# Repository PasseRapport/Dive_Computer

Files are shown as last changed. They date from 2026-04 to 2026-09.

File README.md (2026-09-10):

# Freediving Computer

<p align="center">
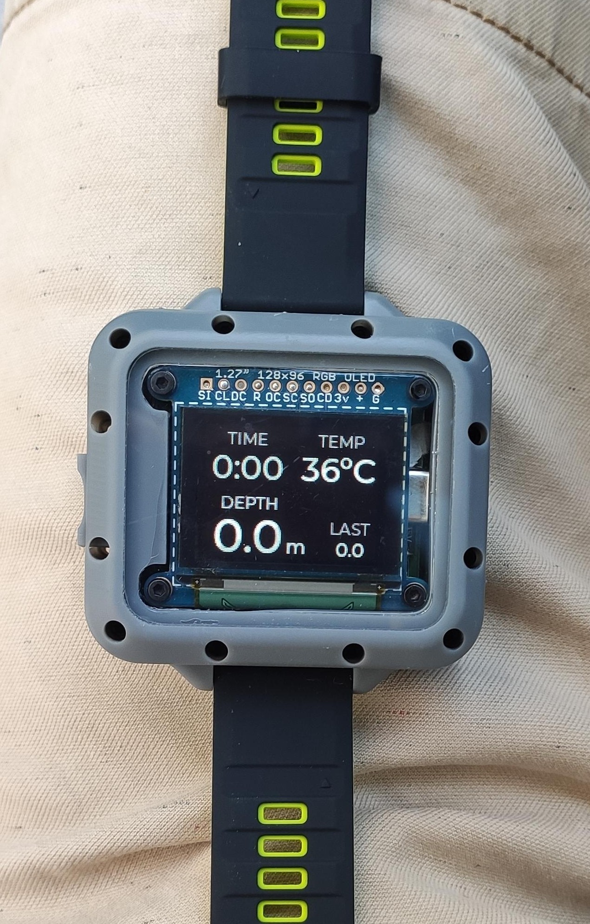
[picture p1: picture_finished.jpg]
Freediving Computer Prototype
  
</p>

A freediving computer prototype I built to test two main ideas: **tap navigation via accelerometer** and **wireless charging** in a completely sealed case.

As a maker, building waterproof buttons and moving parts that survive water pressure without leaking is nearly impossible. To avoid leaks, I skipped physical buttons and external connectors entirely:
1. **Tap navigation** — tapping the case scrolls and selects menus; the accelerometer detects the shock direction.
2. **Wireless charging** — sealed inside the case with an LTC4120 receiver, powered by a custom induction dock.
3. **Magnetic power switch** — an external magnet disconnects the battery so it doesn't drain when stored.
4. **Custom 4-layer PCB** — designed around the form factor of an off-the-shelf color OLED module.

> **Status**: This V1 worked and proved the concept. I am now working on a **V2** that is more compact, with better integration and additional features.

---

## Demo

<p align="center">
  UI Navigation Demo
</p>

<p align="center"><em>Tap-based navigation through the interface — accelerometer detects directional impacts on the casing.</em></p>

<p align="center">
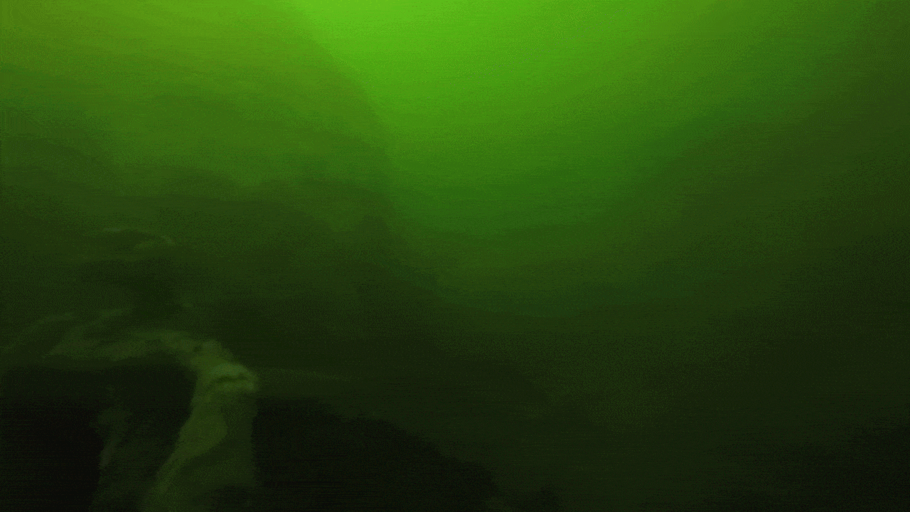
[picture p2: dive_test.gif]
Dive Test
  
</p>

<p align="center"><em>Live depth tracking during a test — automatic dive detection and surface recovery timer.</em></p>

---

## Key Features

| Category | Details |
|---|---|
| **Depth & Temperature** | Real-time tracking via MS5837-30BA (±2 mm resolution, 300–1200 hPa). Automatic fresh/salt water density compensation. |
| **Dive State Machine** | Auto-triggers at 1.0 m depth. Tracks dive time, max depth per dive, and session statistics. |
| **Surface Recovery Timer** | Starts automatically on surfacing. Color-coded: red until 2× dive time, then green. Auto-hides after 10 min. |
| **Session Statistics** | Max dive time, max depth, total dives, and device run time — all tracked per session. |
| **Tap Navigation** | LIS2DUX12 accelerometer detects directional taps on the casing. Left/right to scroll, down to select. No buttons, no dynamic seals. |
| **Magnetic Battery Cutoff** | Integrated magnetic switch isolates the LiPo battery with an external magnet (true 0 µA shelf storage while sealed). |
| **Wireless Charging** | Completely sealed enclosure — power delivered through the case via LTC4120 wireless power receiver. |
| **Display** | 1.27" SSD1351 color OLED (128×96), driven over SPI with DMA. LVGL handles 60 fps animated transitions. |
| **Battery Monitoring** | ADC with hardware calibration curve. Voltage divider maps LiPo range (3.0–4.2 V) to percentage. |
| **Deep Sleep** | Full power-off via menu. GPIO wakeup from accelerometer interrupt. OLED and SPI bus shut down cleanly. |

---

## Mechanical Design

The housing is a two-part sandwich assembly designed without push-buttons, external connectors, or dynamic seals. Waterproofing relies entirely on static seals: a perimeter O-ring evenly compressed between the two halves by 12 M2 screws, and a front protective glass bonded with UV-cure resin. The only physical control is an external magnetic slider that switches power through the solid case wall without any hull penetration.

<p align="center">
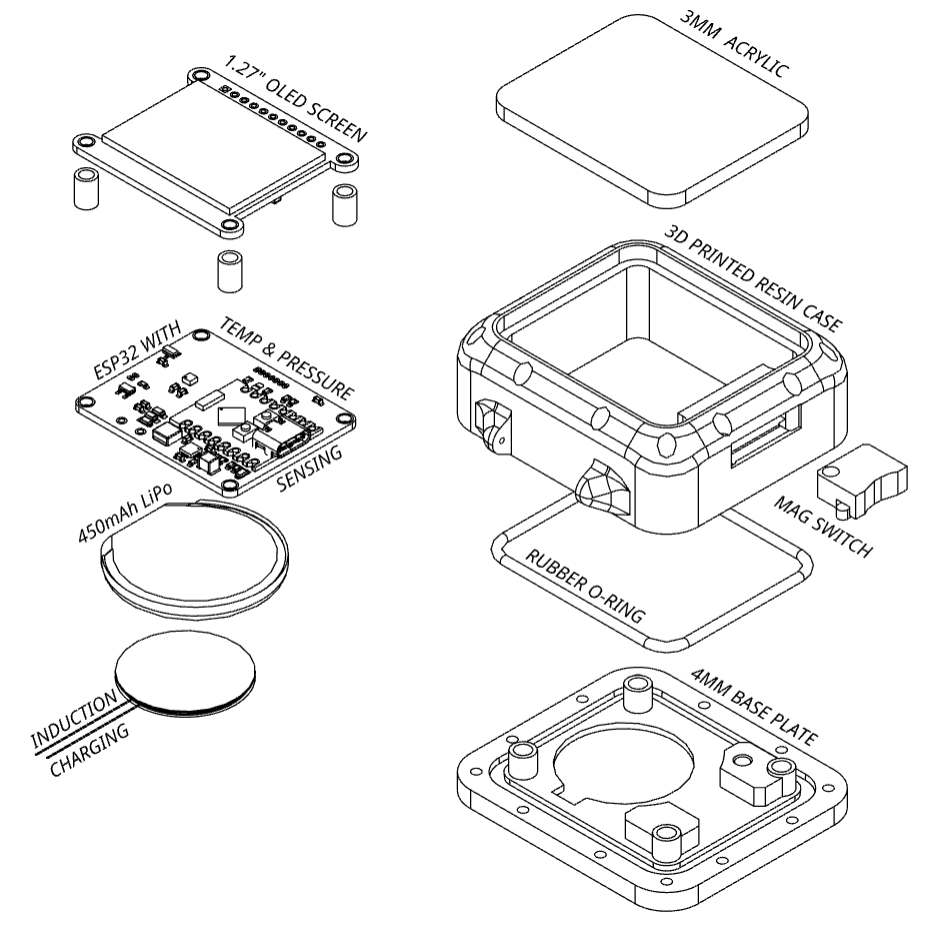
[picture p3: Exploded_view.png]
Exploded View of the Enclosure
  
</p>

<p align="center">
  <a href="https://cad.onshape.com/documents/cc2f090fad22f578b68190d0/w/ffbf50c58a8e366da5acdcdc/e/88baec5796e801b1a2b4a1f3">
    View the 3D model on Onshape ↗
  </a>
</p>

---

## Hardware Architecture

The electronics are split between the wrist unit and a dedicated charging dock.

### 1. Dive Computer Board (Wrist Unit)

The core electronics are built around a custom **4-layer PCB** designed in KiCad, dimensioned to mate directly with an off-the-shelf color OLED module:

- **Form Factor & Display**: Sourced a compact 1.27" 128×96 color OLED module (SSD1351 controller, SPI) and tailored the custom 4-layer PCB and enclosure footprint around this geometry.
- **MCU**: ESP32-C3 (RISC-V core, low power modes, BLE).
- **Pressure Sensor**: TE MS5837-30BA (gel-protected submersible pressure & temperature sensor on I2C).
- **Accelerometer**: ST LIS2DUX12 (ultra-low-power, configured for shock/tap detection with hardware interrupt).
- **Wireless Power Receiver**: Analog Devices LTC4120 with an internal Würth planar receiver coil (WE-WPCC-RX), delivering CC/CV charging to the internal 3.7V LiPo cell.
- **Magnetic Power Switch**: Integrated Hall-effect sensor / magnetic switch controlling a P-MOSFET gate, enabling complete physical battery disconnection via an external magnet without unsealing the housing.

| Component | Part | Role |
|---|---|---|
| MCU | ESP32-C3 | RISC-V core, sensor aggregation, LVGL rendering |
| Pressure Sensor | MS5837-30BA | Absolute pressure & temperature (I2C @ 100 kHz) |
| Accelerometer | LIS2DUX12 | Tap detection with hardware interrupt (I2C) |
| Wireless Charger RX | LTC4120 | Wireless power receiver & CC/CV LiPo charger |
| Magnetic Disconnect | A1102 + P-MOS | Physical battery isolation via external magnet (0 µA storage) |
| Display Module | SSD1351 (Off-the-shelf) | 1.27" 128×96 color OLED (SPI with DMA) |
| Battery | LiPo 3.7V | Single cell, monitored via calibrated ADC voltage divider |

### 2. Wireless Charger Dock (Transmitter)

A companion transmitter base powered via USB-C:

| Component | Part | Role |
|---|---|---|
| Transmitter IC | LTC4125 | 5W AutoResonant wireless power transmitter |
| Transmit Coil | Würth WE-WPCC-TX | 24 µH primary coil for inductive power transfer |
| Input | USB-C (5V) | Power supply |

Source files (KiCad projects, gerbers, BOM): [`Hardware/V1/`](Hardware/V1/)

---

## Software Architecture

The firmware is written in **C** on **ESP-IDF** with **FreeRTOS**. The codebase follows an MVC pattern:

```
Software/DiveComputer/main/
├── main.c                  # App entry, event loop, screen state machine
├── components/
│   ├── pressure_sensor.c   # MS5837 driver, depth calculation, calibration
│   ├── accelerometer.c     # LIS2DUX12 tap detection (ISR + burst analysis)
│   ├── battery.c           # ADC with hardware calibration curve
│   └── oled_display.c      # SSD1351 init, SPI+DMA, LVGL driver
└── ui/
    ├── ui_model.h          # Global state structure (dive_state_t)
    ├── ui_controller.c     # Dive logic, timers, brightness control
    ├── ui_layout.c         # All LVGL screens and refresh functions
    └── ui_layout.h         # Public UI API
```

### Task Model

| Task | Core | Priority | Rate | Role |
|---|---|---|---|---|
| `dive_sensor_task` | 1 | 5 | 4 Hz | Reads pressure sensor, computes depth, updates model |
| `lvgl_port_task` | 0 | 5 | 100 Hz | LVGL rendering and screen refresh |
| `tap_analyzer_task` | 0 | 10 | Event-driven | Wakes on accelerometer interrupt, analyzes shock direction |
| Main loop | 0 | 1 | 50 Hz | Polls tap events, drives screen state machine |

### Dive State Machine

```
                 depth > 1.0m
   ┌──────────┐ ───────────────> ┌──────────┐
   │ SURFACE  │                  │  DIVING  │ <──────┐
   └──────────┘                  └──────────┘        │
        ^                             │              │ depth > 1.0m
        │                             │ depth < 0.3m │ (next dive)
        │                             v              │
        │                      ┌─────────────┐       │
        └───────────────────── │  POST-DIVE  │ ──────┘
           recovery >= 10 min  │ (Recovery)  │
                               └─────────────┘

```

### Tap Detection Pipeline

The accelerometer's hardware tap interrupt wakes the ESP32, which performs a 100-sample burst read (~10 ms) to capture the full shock waveform. The axis with the largest amplitude delta wins, and its sign determines the direction. A 2000-unit noise floor filter rejects accidental vibrations.

```
[HW Interrupt] ──> [ISR Queue] ──> [Burst Read (100 samples)] ──> [Axis Analysis] ──> [Direction Filter] ──> [UI Event]
```

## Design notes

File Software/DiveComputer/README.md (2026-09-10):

# Firmware — Freediving Computer (PoC)

ESP-IDF firmware for the freediving computer Proof of Concept (PoC). Targets the **ESP32-C3** (RISC-V, single core, BLE).

## Quick Start

```bash
# Requires ESP-IDF v5.x
idf.py set-target esp32c3
idf.py build
idf.py -p COMx flash monitor
```

## Architecture

The firmware follows an **MVC pattern** with FreeRTOS task isolation:

- **Model** (`ui_model.h`) — Single `dive_state_t` struct holding all system state (depth, temperature, dive timers, settings). Shared across tasks.
- **View** (`ui_layout.c`) — All LVGL screen definitions and refresh functions. Pure rendering, no logic.
- **Controller** (`ui_controller.c`) — Dive detection state machine, recovery timer logic, brightness control. Runs as LVGL timer callbacks.

### Peripherals

| Driver | File | Bus | Frequency |
|---|---|---|---|
| MS5837-30BA (pressure) | `pressure_sensor.c` | I2C @ 100 kHz | 4 Hz continuous |
| LIS2DUX12 (accelerometer) | `accelerometer.c` | I2C @ 100 kHz | Event-driven (ISR) |
| SSD1351 (OLED) | `oled_display.c` | SPI @ 14 MHz | 100 Hz LVGL refresh |
| Battery ADC | `battery.c` | ADC1 CH3 | 0.1 Hz (10s interval) |

### Task Layout

| Task | Core | Stack | Priority | Purpose |
|---|---|---|---|---|
| `dive_sensor_task` | 1 | 4 KB | 5 | Pressure reading + depth computation |
| `lvgl_port_task` | 0 | 4 KB | 5 | LVGL timer handler (rendering) |
| `tap_analyzer_task` | 0 | 4 KB | 10 | Shock waveform analysis after ISR wakeup |
| Main loop (`app_main`) | 0 | — | 1 | Event polling + screen navigation FSM |

### Dive Detection

- **Dive start**: `depth > 1.0 m` → timer starts, stats reset
- **Dive end**: `depth < 0.3 m` → session stats updated, recovery timer starts
- **Recovery display**: Red if `surface_time < 2 × dive_time`, green otherwise. Hidden after 10 minutes.

### Tap Detection

The LIS2DUX12 hardware tap interrupt fires on GPIO 0 (positive edge). The ISR pushes to a FreeRTOS queue. The analyzer task then burst-reads 100 acceleration samples in ~10 ms, computes the delta (max − min) on each axis, and routes the dominant axis + sign to the UI event system.

Noise floor: deltas below 2000 raw units are discarded.

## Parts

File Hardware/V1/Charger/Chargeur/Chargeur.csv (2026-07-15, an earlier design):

Reference | Qty | Value | DNP | Exclude from BOM | Exclude from Board | Footprint | Datasheet
C0 | 1 | 100 nF |  |  |  | Capacitor_THT_Wurth:C_Wurth_WCAP-FTBP-P7.5L10.5W5H11 | https://www.we-online.com/catalog/datasheet/890443322001CS.pdf?ki
C1,C2 | 2 | 0.1u |  |  |  | Capacitor_SMD:C_0603_1608Metric
C3 | 1 | 4.7n |  |  |  | Capacitor_SMD:C_0603_1608Metric
C4 | 1 | 470p |  |  |  | Capacitor_SMD:C_0603_1608Metric
C5,C6 | 2 | 10n |  |  |  | Capacitor_SMD:C_0603_1608Metric
C7,C8 | 2 | 47u |  |  |  | Capacitor_SMD:C_0603_1608Metric
D1 | 1 | D_Schottky_Small |  |  |  | Diode_SMD:D_MicroSMP_LargeCathode
D2 | 1 | D_Small_Filled |  |  |  | Diode_SMD:D_SOD-523
D3 | 1 | 3535_150353BS74500 |  |  |  | LED_SMD_Wurth:D_Wurth_WL-SMDC-3535 | https://www.we-online.com/catalog/datasheet/150353BS74500.pdf?ki
J1 | 1 | USB_C_Receptacle_PowerOnly_6P |  |  |  | Connector_USB:USB_C_Receptacle_GCT_USB4125-xx-x-0190_6P_TopMnt_Horizontal | https://www.usb.org/sites/default/files/documents/usb_type-c.zip
L1 | 1 | 24.0 uH |  |  |  | Inductor_THT_Wurth:L_Wurth_WE-WPCC-TX_760308101107 | https://www.we-online.com/catalog/datasheet/760308101107.pdf?ki
R1,R9,R10 | 3 | 100k |  |  |  | Resistor_SMD:R_0603_1608Metric
R2 | 1 | <5.23k |  |  |  | Resistor_SMD:R_0603_1608Metric
R3 | 1 | 348k |  |  |  | Resistor_SMD:R_0603_1608Metric
R4,R5 | 2 | 10k |  |  |  | Resistor_SMD:R_0603_1608Metric
R6 | 1 | 11.3k |  |  |  | Resistor_SMD:R_0603_1608Metric
R7 | 1 | 59k |  |  |  | Resistor_SMD:R_0603_1608Metric
R8 | 1 | 7.87k |  |  |  | Resistor_SMD:R_0603_1608Metric
R11 | 1 | 2k |  |  |  | Resistor_SMD:R_0603_1608Metric
R12,R15 | 2 | 5.1k |  |  |  | Resistor_SMD:R_0603_1608Metric
R13,R14 | 2 | 10 mohm |  |  |  | Resistor_SMD_Wurth:R_Wurth_WRIS-PSMB-1206_L3.2W1.6H0.28 | https://www.we-online.com/catalog/datasheet/580060732021.pdf?ki
U1 | 1 | LTC4125 |  |  |  | Package_DFN_QFN:QFN-20-1EP_4x5mm_P0.5mm_EP2.65x3.65mm | https://www.analog.com/media/en/technical-documentation/data-sheets/4125f.pdf

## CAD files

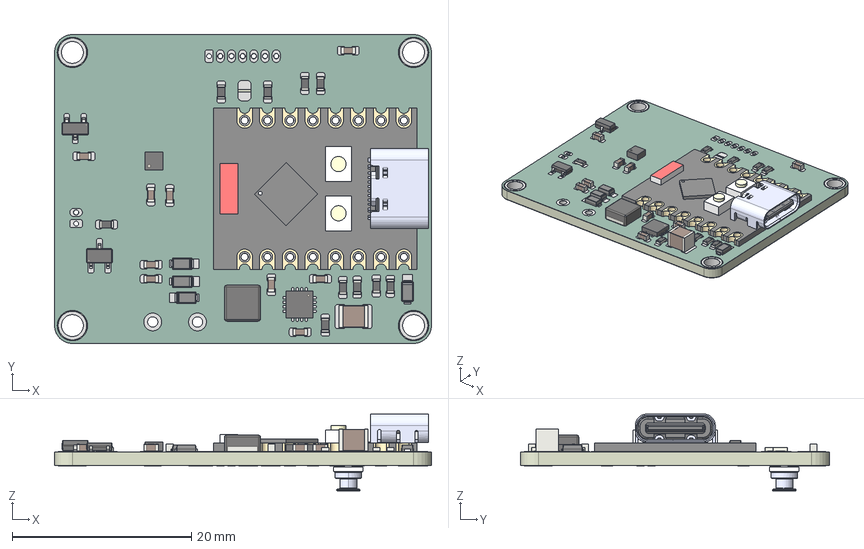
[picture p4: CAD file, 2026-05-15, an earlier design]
Hardware/V1/Computer/DiveComputer.step
42.1 x 34.5 x 8.59 mm
R_0603_1608Metric x 10
C_0603_1608Metric x 9
MSMP20A-M3_89A x 4
C_1210_3225Metric
TSOT-23
SOT-23
QFN-16-1EP_3x3mm_P0.5mm_EP1.7x1.7mm
Board c3mini
USB C
components (other)^ESP32-C3 SuperMini
L_APV_ANR4018
LGA-12_2x2mm_P0.5mm
MS583730BA01-50_MS583730BA01-50
Dive_Computer_pad
Dive_Computer_soldermask x 2
Dive_Computer_PCB

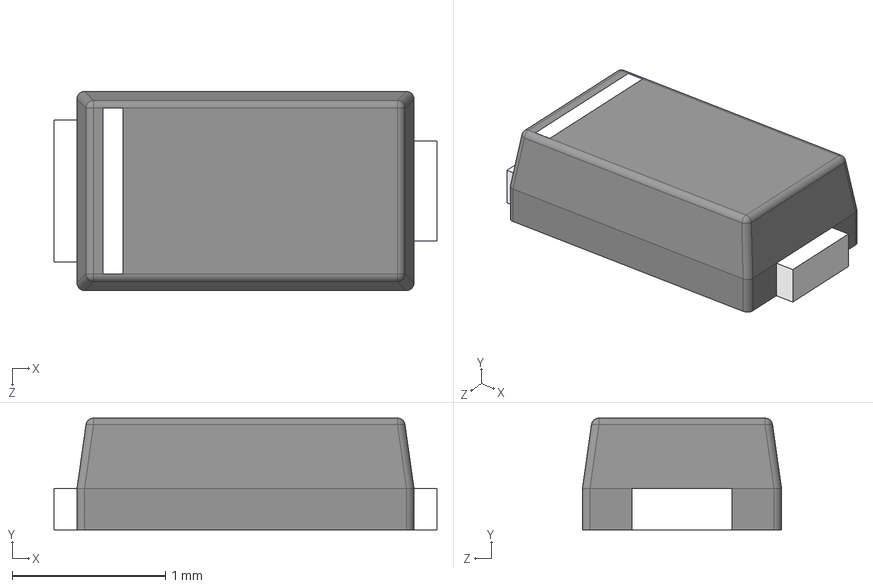
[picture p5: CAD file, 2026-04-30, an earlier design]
Hardware/V1/Computer/3d files/MSMP20A-M3_89A.STEP
2.50 x 0.73 x 1.30 mm

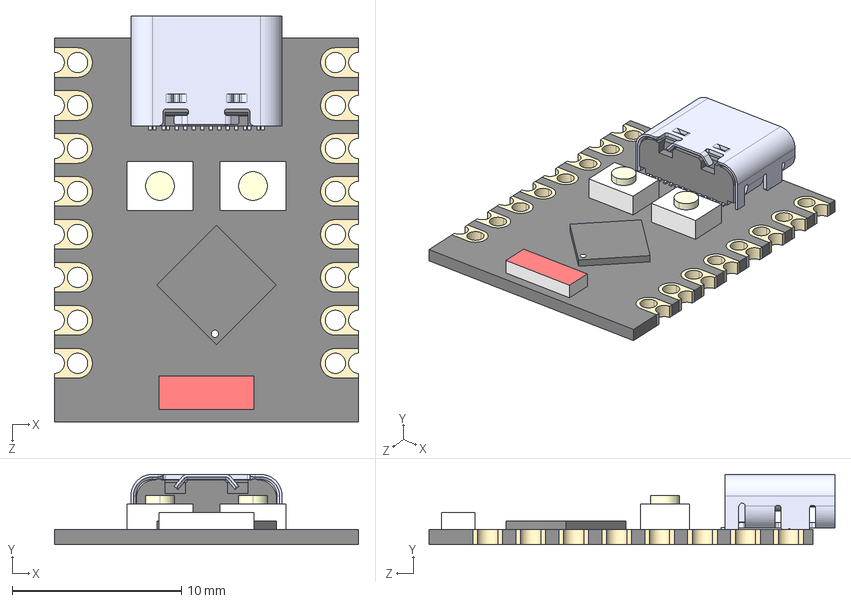
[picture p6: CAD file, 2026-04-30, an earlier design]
Hardware/V1/Computer/3d files/ESP32-C3 SuperMini_TH--3DModel-STEP-56544.STEP
18.0 x 4.16 x 24.0 mm
Board c3mini
USB C
components (other)^ESP32-C3 SuperMini

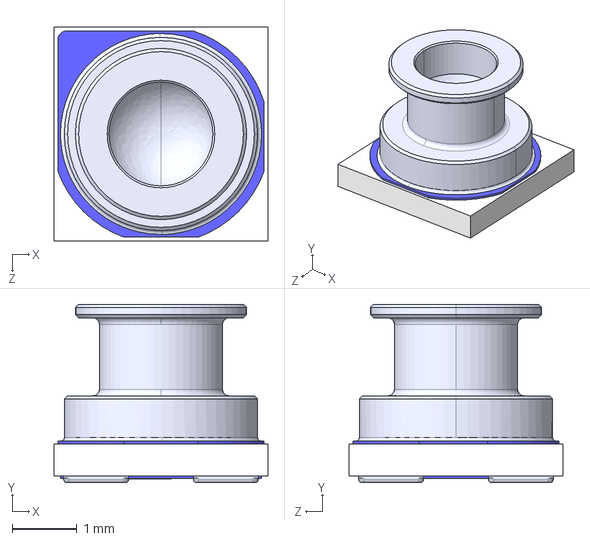
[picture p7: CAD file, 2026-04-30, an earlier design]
Hardware/V1/Computer/3d files/MS583730BA01-50--3DModel-STEP-510211.STEP
3.30 x 2.75 x 3.30 mm

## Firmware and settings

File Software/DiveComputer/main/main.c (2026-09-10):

#include <stdio.h>
#include "freertos/FreeRTOS.h"
#include "freertos/task.h"
#include "driver/gpio.h"
#include "esp_log.h"
#include "oled_display.h"
#include "ui_layout.h"
#include "ui_controller.h"
#include "ui_model.h"          // Ajouté pour accéder au type dive_state_t
#include "pressure_sensor.h" 
#include "accelerometer.h"
#include "esp_sleep.h"
#include "battery.h"

static const char *TAG = "DiveComputer";

// Permet à main.c d'accéder à la variable d'état globale définie dans ui_controller.c
extern dive_state_t system_state;

int16_t acc_x, acc_y, acc_z;

// --- Variables d'état de l'interface ---
typedef enum {
    SCREEN_MAIN,
    SCREEN_STATS,
    SCREEN_WATER_TYPE,
    SCREEN_BRIGHTNESS,
    SCREEN_SLEEP
} app_screen_t;

// --- Système d'événements des Taps ---
typedef enum {
    TAP_NONE = 0,
    TAP_LEFT,   // X+
    TAP_RIGHT,  // X-
    TAP_ACTION  // Z-
} tap_event_t;

// Variable globale pour stocker l'événement en attente
volatile tap_event_t current_tap_event = TAP_NONE;

// Nouvelle fonction de communication (Appelée par accelerometer.c)
void send_tap_event(char axis, bool is_positive) {
    if (axis == 'X' && is_positive) {
        current_tap_event = TAP_LEFT;
    } else if (axis == 'X' && !is_positive) {
        current_tap_event = TAP_RIGHT;
    } else if (axis == 'Y' && !is_positive) {
        current_tap_event = TAP_ACTION;
    }
}


void enter_deep_sleep() {
    ESP_LOGI(TAG, "Mise en veille profonde imminente...");

    // 1. Éteindre l'écran OLED
    oled_display_power_off();

    gpio_reset_pin(GPIO_NUM_8);
    gpio_reset_pin(GPIO_NUM_9);

    vTaskDelay(pdMS_TO_TICKS(1000));

    // 2. Dire à l'ESP32 quelle broche va le réveiller.
   esp_deep_sleep_enable_gpio_wakeup((1ULL << GPIO_NUM_0), ESP_GPIO_WAKEUP_GPIO_HIGH);

    ESP_LOGI(TAG, "Bonne nuit ! 💤");

    // 3. Coupure du processeur
    esp_deep_sleep_start();
}

void app_main(void)
{
    ESP_LOGI(TAG, "Booting Dive Computer...");

    // 1. Initialisation matérielle et UI
    init_oled_display();
    set_display_brightness(15);
    build_ui_state_machine();
    init_ui_controllers();

    // 2. Initialisation des capteurs
    init_dive_sensor();
    calibrate_surface_pressure();
    init_battery_adc();
    
    // Initialise et lance l'écoute des Taps (FSM / Smart Tap)
    init_accelerometer(); 

    // Lance la lecture de la pression en tâche de fond (Core 1)
    xTaskCreatePinnedToCore(dive_sensor_task, "SensorTask", 4096, NULL, 5, NULL, 1);

    // 3. Variables pour la machine d'état des écrans
    app_screen_t current_screen = SCREEN_MAIN; 

    // 4. Boucle Principale
    while(1) {
        
        // Si un événement Tap a été reçu
        if (current_tap_event != TAP_NONE) {
            
            // On sauvegarde l'événement et on libère le drapeau immédiatement
            tap_event_t action = current_tap_event;
            current_tap_event = TAP_NONE; 
            
           
            // --- ACTION : DEFILER VERS LA DROITE ---
            if (action == TAP_RIGHT) {
                ESP_LOGI(TAG, "👉 Navigation Droite");
                if (current_screen == SCREEN_MAIN) {
                    ui_slide_pages(main_screen, stats_screen);
                    current_screen = SCREEN_STATS;
                } else if (current_screen == SCREEN_STATS) {
                    ui_slide_pages(stats_screen, water_screen);
                    current_screen = SCREEN_WATER_TYPE;
                } else if (current_screen == SCREEN_WATER_TYPE) {
                    ui_slide_pages(water_screen, brightness_screen);
                    current_screen = SCREEN_BRIGHTNESS;
                } else if (current_screen == SCREEN_BRIGHTNESS) {
                    // 👉 On va vers l'écran Sleep
                    ui_slide_pages(brightness_screen, sleep_screen); 
                    current_screen = SCREEN_SLEEP;
                } else if (current_screen == SCREEN_SLEEP) {
                    // 👉 On boucle vers le Main
                    ui_slide_pages(sleep_screen, main_screen); 
                    current_screen = SCREEN_MAIN;
                }
            } 
            // --- ACTION : DEFILER VERS LA GAUCHE ---
            else if (action == TAP_LEFT) {
                ESP_LOGI(TAG, "👈 Navigation Gauche");
                if (current_screen == SCREEN_MAIN) {
                    // 👉 On va vers l'écran Sleep à l'envers
                    ui_slide_pages(main_screen, sleep_screen);
                    current_screen = SCREEN_SLEEP;
                } else if (current_screen == SCREEN_SLEEP) {
                    // 👉 On recule vers Brightness
                    ui_slide_pages(sleep_screen, brightness_screen);
                    current_screen = SCREEN_BRIGHTNESS;
                } else if (current_screen == SCREEN_BRIGHTNESS) {
                    ui_slide_pages(brightness_screen, water_screen);
                    current_screen = SCREEN_WATER_TYPE;
                } else if (current_screen == SCREEN_WATER_TYPE) {
                    ui_slide_pages(water_screen, stats_screen);
                    current_screen = SCREEN_STATS;
                } else if (current_screen == SCREEN_STATS) {
                    ui_slide_pages(stats_screen, main_screen);
                    current_screen = SCREEN_MAIN;
                }
            }
            // --- ACTION : VALIDER / CHANGER ---
            else if (action == TAP_ACTION) {
                ESP_LOGI(TAG, "👇 Action de Validation");
                
                if (current_screen == SCREEN_SLEEP) {
                    // 👉 LE DÉCLENCHEUR DU DEEP SLEEP
                    enter_deep_sleep();
                    
                } else if (current_screen == SCREEN_WATER_TYPE) {
                    ESP_LOGI(TAG, "Changement du type d'eau !");
                    system_state.is_salt_water = !system_state.is_salt_water;
                    ui_refresh_water_selection(system_state.is_salt_water);
                    
                } else if (current_screen == SCREEN_BRIGHTNESS) {
                    ESP_LOGI(TAG, "Changement de luminosité !");
                    uint8_t new_lvl = system_state.brightness_lvl + 1;
                    if (new_lvl > 5) new_lvl = 1;
                    handle_brightness_change(new_lvl);
                    
                } else {
                    ESP_LOGI(TAG, "Rien à valider sur cet écran.");
                }
            }
        }

        // --- Optionnel : Lecture continue pour Teleplot (commenté si non utilisé) ---
        /*
        if (get_acceleration(&acc_x, &acc_y, &acc_z) == ESP_OK) {
            //printf(">AccX_g:%.3f\n", acc_x * 0.000244f);
            //printf(">AccY_g:%.3f\n", acc_y * 0.000244f);
            //printf(">AccZ_g:%.3f\n", acc_z * 0.000244f);
        }
        */

        // Petite pause pour laisser respirer le processeur
        vTaskDelay(pdMS_TO_TICKS(20));
    }
}

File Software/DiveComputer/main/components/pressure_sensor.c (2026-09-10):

#include "pressure_sensor.h"
#include "ui_model.h"
#include "driver/i2c.h"
#include "esp_log.h"
#include "freertos/FreeRTOS.h"
#include "freertos/task.h"

static const char *TAG = "MS5837";

// --- Configuration I2C pour ESP32-C3 ---
#define I2C_MASTER_SCL_IO           9    
#define I2C_MASTER_SDA_IO           8   
#define I2C_MASTER_NUM              0    
#define I2C_MASTER_FREQ_HZ          100000 
#define I2C_MASTER_TIMEOUT_MS       100

// --- Commandes du MS5837-30BA ---
#define MS5837_ADDR                 0x76
#define MS5837_RESET                0x1E
#define MS5837_ADC_READ             0x00
#define MS5837_PROM_READ            0xA0
#define MS5837_CONVERT_D1_8192      0x4A 
#define MS5837_CONVERT_D2_8192      0x5A 

// Variables globales
static uint16_t C[8]; 
static float surface_pressure_hPa = 1013.25f; 

// --- Fonctions I2C Bas niveau ---

static esp_err_t ms5837_write_command(uint8_t cmd) {
    i2c_cmd_handle_t handle = i2c_cmd_link_create();
    i2c_master_start(handle);
    i2c_master_write_byte(handle, (MS5837_ADDR << 1) | I2C_MASTER_WRITE, true);
    i2c_master_write_byte(handle, cmd, true);
    i2c_master_stop(handle);
    esp_err_t ret = i2c_master_cmd_begin(I2C_MASTER_NUM, handle, pdMS_TO_TICKS(I2C_MASTER_TIMEOUT_MS));
    i2c_cmd_link_delete(handle);
    return ret;
}

static esp_err_t ms5837_read_prom(uint8_t reg, uint16_t *value) {
    ms5837_write_command(MS5837_PROM_READ + (reg * 2));
    uint8_t buf[2] = {0};
    i2c_cmd_handle_t handle = i2c_cmd_link_create();
    i2c_master_start(handle);
    i2c_master_write_byte(handle, (MS5837_ADDR << 1) | I2C_MASTER_READ, true);
    i2c_master_read(handle, buf, 2, I2C_MASTER_LAST_NACK);
    i2c_master_stop(handle);
    esp_err_t ret = i2c_master_cmd_begin(I2C_MASTER_NUM, handle, pdMS_TO_TICKS(I2C_MASTER_TIMEOUT_MS));
    i2c_cmd_link_delete(handle);
    *value = (buf[0] << 8) | buf[1];
    return ret;
}

static esp_err_t ms5837_read_adc(uint32_t *value) {
    ms5837_write_command(MS5837_ADC_READ);
    uint8_t buf[3] = {0};
    i2c_cmd_handle_t handle = i2c_cmd_link_create();
    i2c_master_start(handle);
    i2c_master_write_byte(handle, (MS5837_ADDR << 1) | I2C_MASTER_READ, true);
    i2c_master_read(handle, buf, 3, I2C_MASTER_LAST_NACK);
    i2c_master_stop(handle);
    esp_err_t ret = i2c_master_cmd_begin(I2C_MASTER_NUM, handle, pdMS_TO_TICKS(I2C_MASTER_TIMEOUT_MS));
    i2c_cmd_link_delete(handle);
    *value = (buf[0] << 16) | (buf[1] << 8) | buf[2];
    return ret;
}

// --- Logique Mathématique SÉCURISÉE ---

static bool ms5837_read_and_calculate(float *out_pressure_hPa, float *out_temp_c) {
    uint32_t D1 = 0, D2 = 0;

    // 1. Conversion Pression (D1)
    if (ms5837_write_command(MS5837_CONVERT_D1_8192) != ESP_OK) return false;
    vTaskDelay(pdMS_TO_TICKS(30)); // 30ms = Sécurité absolue contre le décalage des ticks
    if (ms5837_read_adc(&D1) != ESP_OK || D1 == 0) return false;

    // 2. Conversion Température (D2)
    if (ms5837_write_command(MS5837_CONVERT_D2_8192) != ESP_OK) return false;
    vTaskDelay(pdMS_TO_TICKS(30)); 
    if (ms5837_read_adc(&D2) != ESP_OK || D2 == 0) return false;

    // 3. Calculs mathématiques
    int32_t dT = D2 - ((uint32_t)C[5] * 256);
    int32_t TEMP = 2000 + ((int64_t)dT * C[6]) / 8388608;

    int64_t OFF = ((int64_t)C[2] * 65536) + (((int64_t)C[4] * dT) / 128);
    int64_t SENS = ((int64_t)C[1] * 32768) + (((int64_t)C[3] * dT) / 256);

    // Compensation 2nd ordre
    int64_t Ti = 0, OFFi = 0, SENSi = 0;
    if (TEMP < 2000) { 
        Ti = (3 * (int64_t)dT * dT) / 8589934592LL;
        OFFi = 3 * (TEMP - 2000) * (TEMP - 2000) / 2;
        SENSi = 5 * (TEMP - 2000) * (TEMP - 2000) / 8;
        if (TEMP < -1500) { 
            OFFi = OFFi + 7 * (TEMP + 1500) * (TEMP + 1500);
            SENSi = SENSi + 4 * (TEMP + 1500) * (TEMP + 1500);
        }
    } else { 
        Ti = 2 * ((int64_t)dT * dT) / 137438953472LL;
        OFFi = 1 * (TEMP - 2000) * (TEMP - 2000) / 16;
        SENSi = 0;
    }

    TEMP = TEMP - Ti;
    OFF = OFF - OFFi;
    SENS = SENS - SENSi;

    int32_t P = (((D1 * SENS) / 2097152) - OFF) / 8192;

    *out_pressure_hPa = (float)P / 10.0f;
    *out_temp_c = (float)TEMP / 100.0f;
    return true;
}

// --- Fonctions Publiques ---

void init_dive_sensor(void) {
    i2c_config_t conf = {
        .mode = I2C_MODE_MASTER,
        .sda_io_num = I2C_MASTER_SDA_IO,
        .scl_io_num = I2C_MASTER_SCL_IO,
        .sda_pullup_en = GPIO_PULLUP_ENABLE,
        .scl_pullup_en = GPIO_PULLUP_ENABLE,
        .master.clk_speed = I2C_MASTER_FREQ_HZ,
    };
    i2c_param_config(I2C_MASTER_NUM, &conf);
    i2c_driver_install(I2C_MASTER_NUM, conf.mode, 0, 0, 0);

    ms5837_write_command(MS5837_RESET);
    vTaskDelay(pdMS_TO_TICKS(20)); // Laisse bien le temps au capteur de booter

    for (uint8_t i = 0; i < 7; i++) {
        ms5837_read_prom(i, &C[i]);
    }
}

void calibrate_surface_pressure(void) {
    ESP_LOGI(TAG, "Calibration de surface...");
    float sum_pressure = 0;
    float current_pressure, current_temp;
    int valid_samples = 0; 

    // On ignore délibérément les 2 premières lectures (poubelle)
    ms5837_read_and_calculate(&current_pressure, &current_temp);
    ms5837_read_and_calculate(&current_pressure, &current_temp);

    for (int i = 0; i < 50; i++) {
        if (ms5837_read_and_calculate(&current_pressure, &current_temp)) {
            sum_pressure += current_pressure;
            valid_samples++;
        }
    }

    if (valid_samples > 0) {
        surface_pressure_hPa = sum_pressure / valid_samples;
        ESP_LOGI(TAG, "Calibrée : %.2f hPa", surface_pressure_hPa);
    } else {
        ESP_LOGE(TAG, "Echec calibration !");
    }
}

void dive_sensor_task(void *pvParameters) {
    float pressure_hPa = 0;
    float temp_celsius = 0;

    while (1) {
        if (ms5837_read_and_calculate(&pressure_hPa, &temp_celsius)) {
            float density = system_state.is_salt_water ? 1025.0f : 1000.0f;
            float gravity = 9.80665f;

            float delta_P_Pa = (pressure_hPa - surface_pressure_hPa) * 100.0f;
            float depth = delta_P_Pa / (density * gravity);
            
            if (depth < 0.0f) depth = 0.0f; 

            system_state.current_depth = depth;
            system_state.temperature = temp_celsius;

            //printf(">Temperature:%.2f\n", system_state.temperature);
           // printf(">Pressure:%.2f\n", pressure_hPa);
           // printf(">Depth:%.3f\n", system_state.current_depth);
        } else {
            ESP_LOGW(TAG, "Erreur lecture I2C ignorée.");
        }
        
        vTaskDelay(pdMS_TO_TICKS(250));
    }
}

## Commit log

2026-04-28 Schematic finished
    [Dive_Computer.kicad_sch]
2026-04-29 Schematic update
    [Dive_Computer.kicad_pcb, Dive_Computer.kicad_sch]
2026-04-30 Routage terminé
    [Dive_Computer.kicad_pcb, Dive_Computer.kicad_sch]
2026-04-30 Added 3D models
    [Dive_Computer-B_Cu.gbr, Dive_Computer-B_Mask.gbr, Dive_Computer-B_Paste.gbr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]
2026-05-15 UI
    The UI is mostly done
    The core architecture is up and running
    [DiveComputer.step, Dive_Computer.kicad_pcb]
2026-05-15 added the software
    [DiveComputer.step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]
2026-07-15 Ibom charger
    [Chargeur-B_Cu.gbr, Chargeur-B_Mask.gbr, Chargeur-B_Paste.gbr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]
2026-09-10 Update firmware to latest version (MS5837, LIS2DUX12 tap detection, battery ADC, UI v2)
2026-09-10 Emphasize maker constraint of pressure-proof moving buttons solved via solid-state design
2026-09-10 Refine mechanical design description with magnetic slider details and maker tone
2026-09-10 Add mechanical assembly details: two-part sandwich, static O-ring, 12 M2 screws, UV resin glass
2026-09-19 updated kicad recovery files
2026-09-19 Started V2 schematic
    [DiveComputerV2.kicad_pcb, DiveComputerV2.kicad_sch]
2026-09-20 added magnetometer & haptic driver
    [DiveComputerV2.kicad_sch, Dive_Computer.kicad_sch]
2026-10-15 V2 complete schematic
2026-10-19 PCB layout
2026-10-27 feat: add bmad testing and framework skills and update firmware simulator files
2026-10-27 test: audit nitrogen coefficients against printed source
2026-10-28 feat(simulator): adjust battery by wheel and center missing-data text
2026-10-28 test(simulator): record second-by-second timer and apnea control evidence
2026-10-28 fix(ostc4): time declared three-metre stop legs exactly
2026-10-29 Show battery above six on Automatique watch dial
2026-10-29 Raise Dauphine battery slightly for balance
